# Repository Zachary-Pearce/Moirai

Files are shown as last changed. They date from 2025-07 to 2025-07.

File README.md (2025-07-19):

<p align="center">
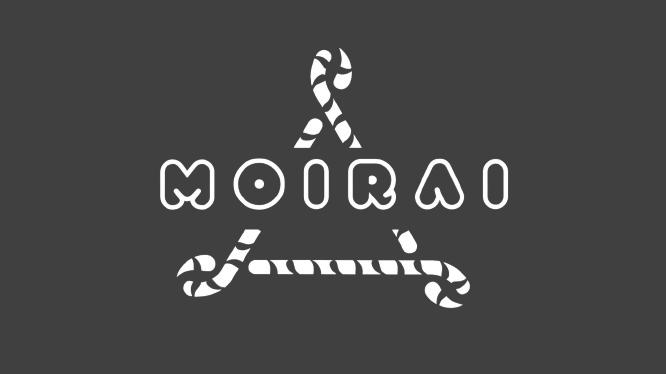
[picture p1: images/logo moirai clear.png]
Moirai Logo

<br>

</p>

Moirai is a 3-Channel majority voter for redundant flight computer systems made with KiCad. It allows you to properly implement redundant systems in hobby rockets whether they be high power or low power.

## Installation
1. Clone the repository:

```bash
git clone https://github.com/Zachary-Pearce/Moirai
```

2. Open the folder in KiCad and confirm the local libraries have been imported.

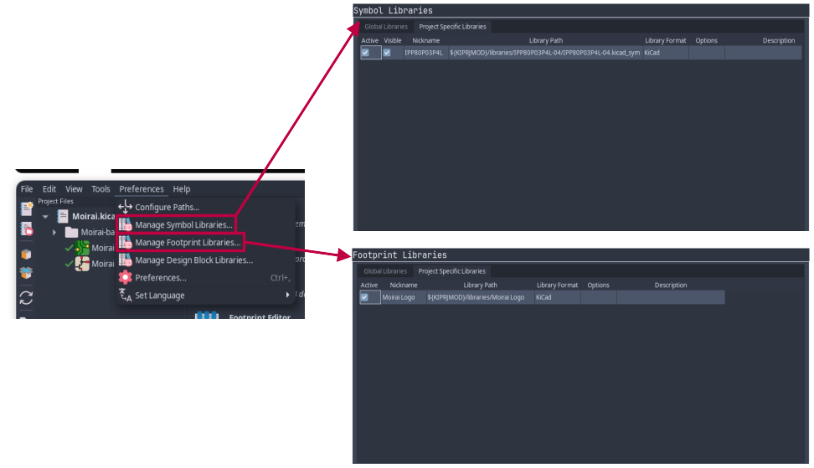
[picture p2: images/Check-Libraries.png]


## Usage
> [!WARNING]
> Rocketry is a dangerous hobby, you are using this device at your own risk, incorrect usage may result in unexpected behaviour.

Before deciding to get this PCB for yourself, I reccomend that you read the full manual present in the wiki.

If you are going to get this PCB cut, I would reccomend using [JLCPCB](https://jlcpcb.com/), when creating your Gerber and Drill files, please follow the [relevant guide](https://jlcpcb.com/help/catalog/180-PCB-Files-Preparation) for your version of KiCad.

## Contributing
1. Fork this repository
2. Clone your fork
3. Make your changes
4. Submit a pull request

Ensure that your pull request includes the following:
- What has changed?
- Why has it changed?
- Proof testing has been carried out to ensure your changes work.

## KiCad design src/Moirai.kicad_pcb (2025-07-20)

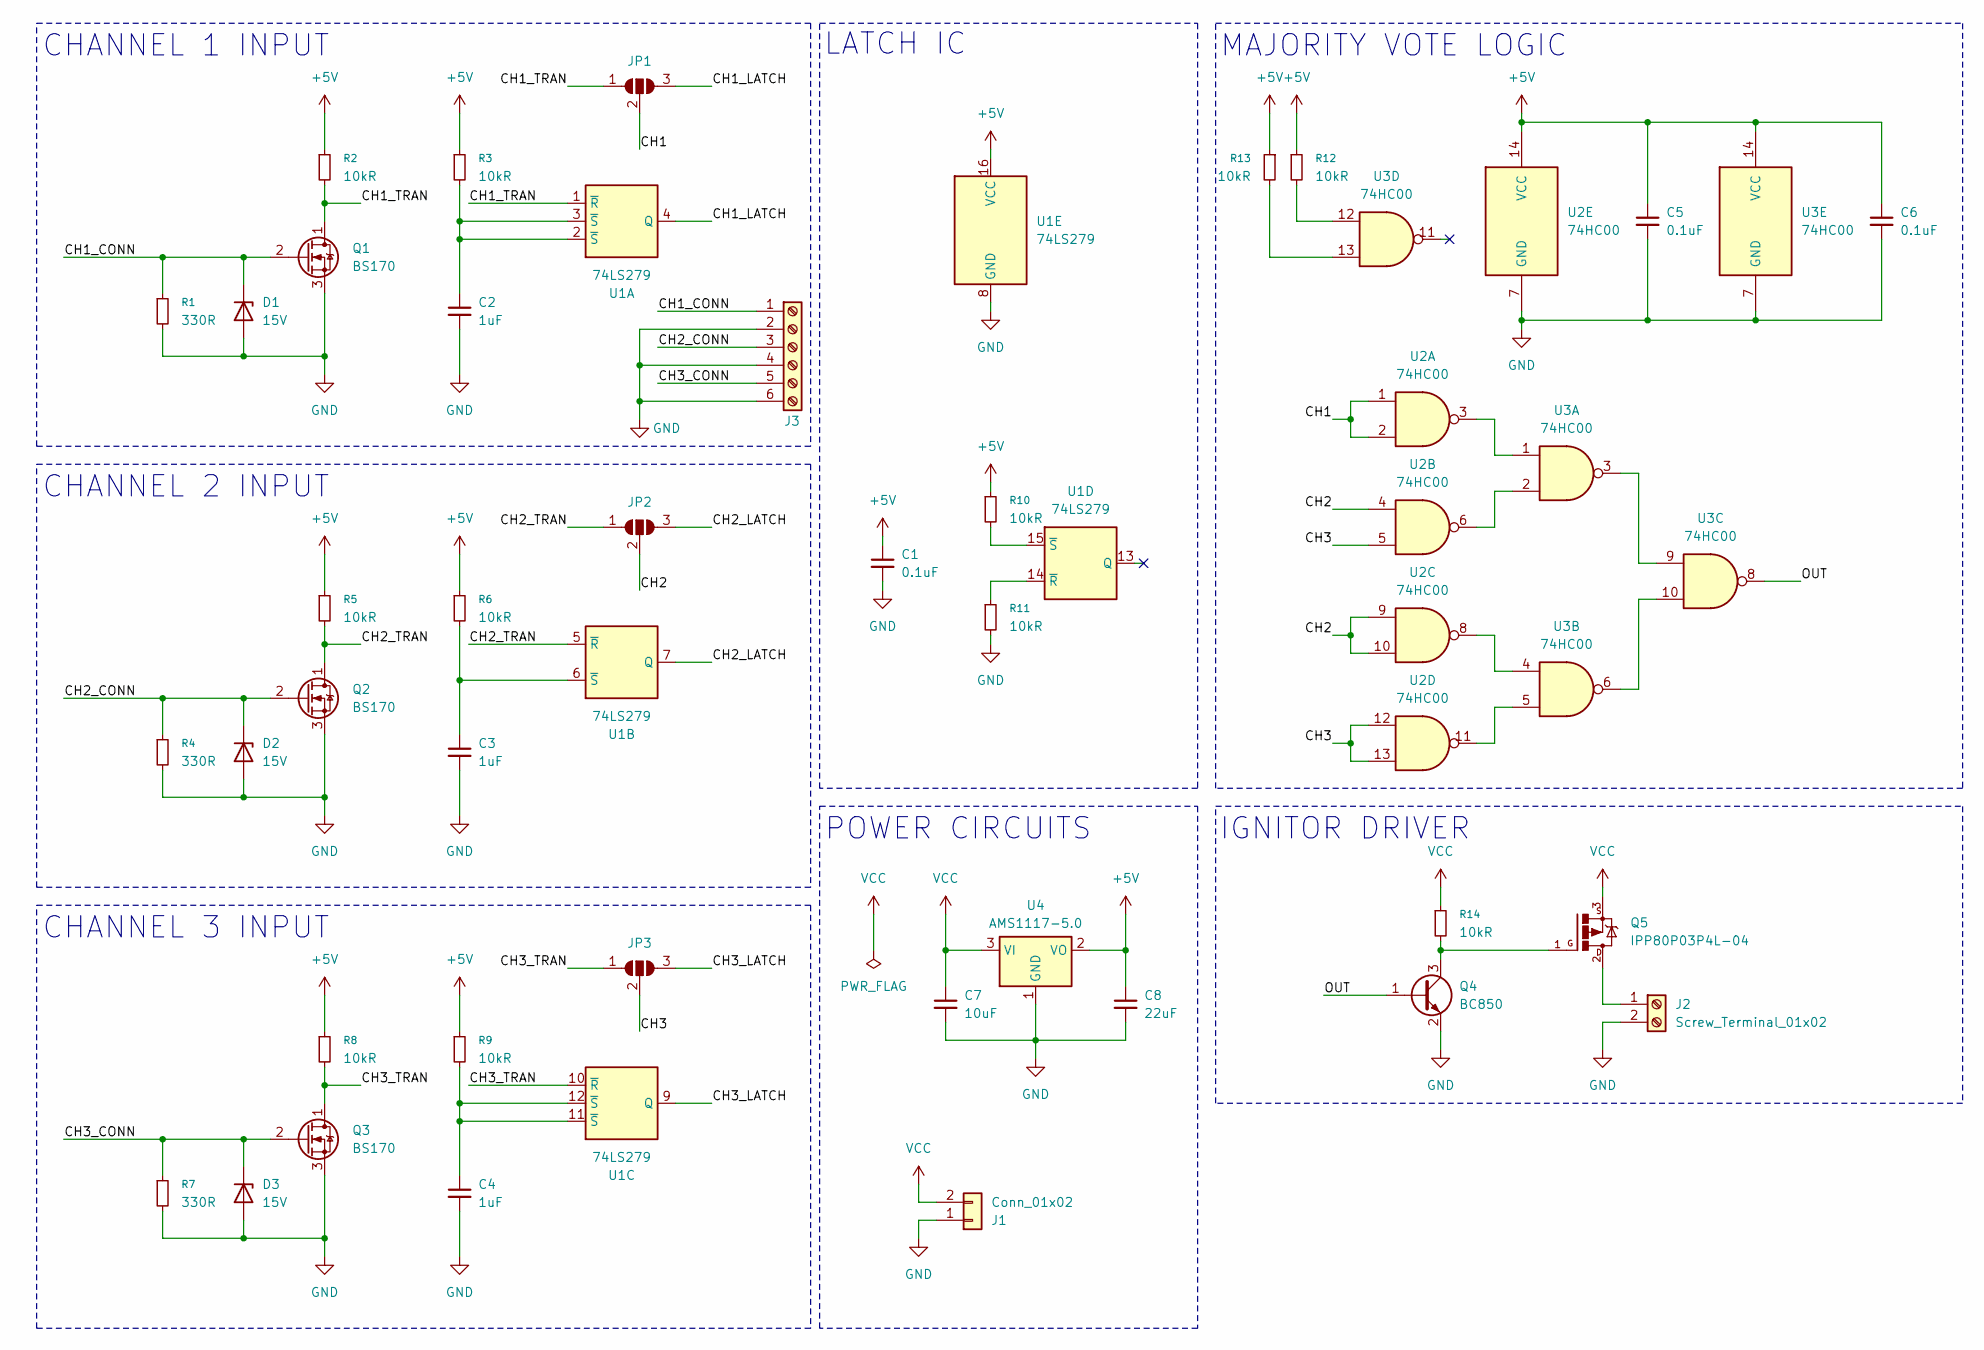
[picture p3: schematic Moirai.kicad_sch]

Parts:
C1, C5, C6: 0.1uF; C_0805_2012Metric
C2, C3, C4: 1uF; C_0805_2012Metric
C7: 10uF; C_0805_2012Metric
C8: 22uF; C_0805_2012Metric
D1, D2, D3: 15V; D_SMA
J1: Conn_01x02; AMASS_XT30U-M_1x02_P5.0mm_Vertical
J2: Screw_Terminal_01x02; TerminalBlock_WAGO_236-402_1x02_P5.00mm_45Degree
J3: Screw_Terminal_01x06; TerminalBlock_WAGO_236-406_1x06_P5.00mm_45Degree
JP1, JP2, JP3: SolderJumper_3_Open; SolderJumper-3_P2.0mm_Open_TrianglePad1.0x1.5mm
Q1, Q2, Q3: BS170; TO-92_Inline
Q4: BC850; SOT-23
Q5: IPP80P03P4L-04; TO-220-3_Vertical
R1, R4, R7: 330R; R_0805_2012Metric
R2, R3, R5, R6, R8, R9, R10, R11, R12, R13, R14: 10kR; R_0805_2012Metric
U1: 74LS279; DIP-16_W7.62mm
U2, U3: 74HC00; DIP-14_W7.62mm
U4: AMS1117-5.0; SOT-223-3_TabPin2

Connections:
+5V: C1.1, C5.1, C6.1, C8.1, R2.1, R3.1, R5.1, R6.1, R8.1, R9.1, R10.1, R12.1, R13.1, U1.16 (VCC), U2.14 (VCC), U3.14 (VCC), U4.2 (VO)
/CH1: JP1.2 (C), U2.1, U2.2
/CH1_CONN: D1.1 (K), J3.1, Q1.2 (G), R1.1
/CH1_LATCH: JP1.3 (B), U1.4 (Q)
/CH1_TRAN: JP1.1 (A), Q1.1 (D), R2.2, U1.1 (~R)
/CH2: JP2.2 (C), U2.4, U2.9, U2.10
/CH2_CONN: D2.1 (K), J3.3, Q2.2 (G), R4.1
/CH2_LATCH: JP2.3 (B), U1.7 (Q)
/CH2_TRAN: JP2.1 (A), Q2.1 (D), R5.2, U1.5 (~R)
/CH3: JP3.2 (C), U2.5, U2.12, U2.13
/CH3_CONN: D3.1 (K), J3.5, Q3.2 (G), R7.1
/CH3_LATCH: JP3.3 (B), U1.9 (Q)
/CH3_TRAN: JP3.1 (A), Q3.1 (D), R8.2, U1.10 (~R)
/OUT: Q4.1 (B), U3.8
GND: C1.2, C2.2, C3.2, C4.2, C5.2, C6.2, C7.2, C8.2, D1.2 (A), D2.2 (A), D3.2 (A), J1.1, J2.2, J3.2, J3.4, J3.6, Q1.3 (S), Q2.3 (S), Q3.3 (S), Q4.2 (E), R1.2, R4.2, R7.2, R11.2, U1.8 (GND), U2.7 (GND), U3.7 (GND), U4.1 (GND)
unnamed: C2.1, R3.2, U1.2 (~S), U1.3 (~S)
unnamed: C4.1, R9.2, U1.11 (~S), U1.12 (~S)
unnamed: J2.1, Q5.2
unnamed: Q4.3 (C), Q5.1, R14.2
unnamed: R12.2, U3.12
unnamed: R13.2, U3.13
unnamed: C3.1, R6.2, U1.6 (~S)
unnamed: R11.1, U1.14 (~R)
unnamed: R10.2, U1.15 (~S)
unnamed: U2.3, U3.1
unnamed: U2.6, U3.2
unnamed: U2.8, U3.4
unnamed: U2.11, U3.5
unnamed: U3.3, U3.9
unnamed: U3.6, U3.10
VCC: C7.1, J1.2, Q5.3, R14.1, U4.3 (VI)

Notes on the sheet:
IGNITOR DRIVER
MAJORITY VOTE LOGIC
CHANNEL 3 INPUT
CHANNEL 1 INPUT
CHANNEL 2 INPUT
LATCH IC
POWER CIRCUITS

Board: 2 copper layers, 40 parts (0 on the bottom side), 31 nets, no tracks yet.

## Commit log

2025-07-09 Added logo and structure
    [Moirai.kicad_pcb, Moirai.kicad_sch]
2025-07-10 updated schematic
    [Moirai.kicad_sch]
2025-07-19 fixed IPP80P symbol
    [Moirai.kicad_sch]
2025-07-20 PCB design
    [Moirai.kicad_pcb, Moirai.kicad_sch]
2025-07-20 PCB update
    [Moirai.kicad_pcb]
